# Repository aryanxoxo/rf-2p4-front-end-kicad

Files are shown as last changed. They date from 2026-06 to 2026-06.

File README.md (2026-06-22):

# 2.4 GHz RF Front-End KiCad Project

> Public archive note: this repository is a portfolio/demo-safe version prepared from private working repositories/materials; sensitive details, credentials, raw logs, and proprietary context are intentionally omitted.

This is a real KiCad project scaffold for a compact 2.4 GHz RF front end, not a portfolio mockup.

## What Is Included

- `rf_2p4_front_end.kicad_pro`: KiCad project file with an RF netclass.
- `rf_2p4_front_end.kicad_pcb`: Two-layer PCB layout with board outline, edge-launch SMA pads, 50 ohm RF routes, 0402 matching parts, SOT-363 RF amplifier footprint, ground pours, and via stitching.
- `rf_2p4_front_end.kicad_sch`: Schematic intent sheet with the RF signal chain and starting component values.
- `stackup_and_tuning_notes.md`: Fabrication, impedance, and VNA tuning notes.

## Stackup Assumption

The PCB is set up for a common low-cost two-layer FR-4 stackup:

- Board thickness: 1.6 mm
- Copper: 1 oz outer
- Dielectric: FR-4, Er about 4.2
- Top RF trace width: 3.0 mm nominal for approximately 50 ohm microstrip over a solid bottom ground plane

If your board house uses a different stackup, update the RF track width before ordering.

## Important Fabrication Notes

Open the project in KiCad and run DRC before fabrication. KiCad is not installed in this Codex environment, so Gerbers were not exported or validated here.

Before ordering, replace the generic SMA edge-launch and SOT-363 amplifier footprints with the exact manufacturer land patterns for your selected connector and RF amplifier. The included geometry is suitable as an editable RF layout starting point.

## Suggested Bring-Up

1. Populate J1/J2, C1, L1, C2, C3, and U1.
2. Start with C1 = 100 pF, L1 = 3.9 nH, C2 = 1.2 pF, C3 = 100 pF.
3. Calibrate the VNA to the SMA reference plane.
4. Measure S11 and S21 from 2.3 GHz to 2.6 GHz.
5. Re-tune L1/C2 to center the match across 2.4 GHz to 2.5 GHz.

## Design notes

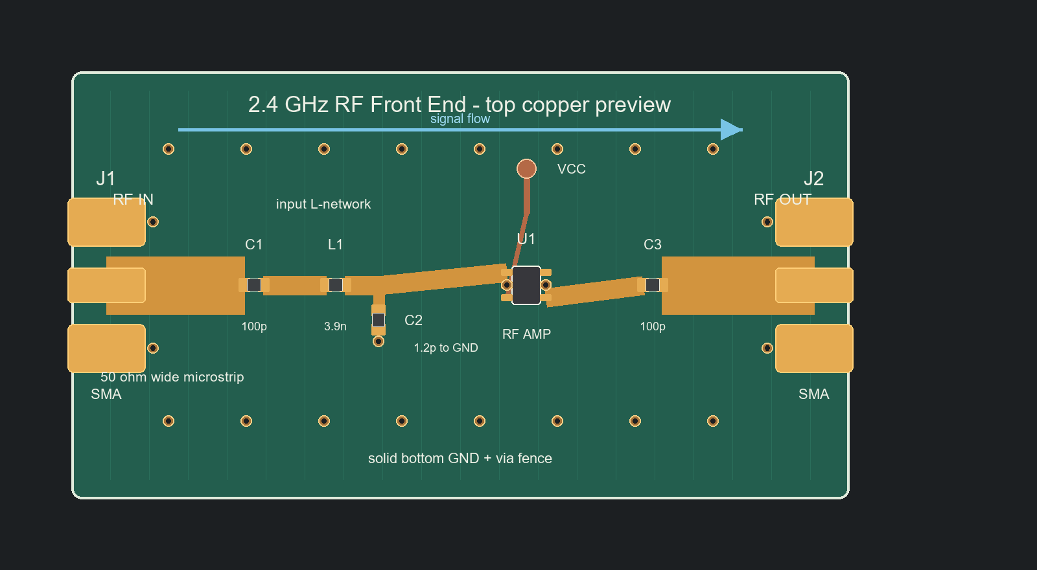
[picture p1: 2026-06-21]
rf_2p4_front_end_preview.png

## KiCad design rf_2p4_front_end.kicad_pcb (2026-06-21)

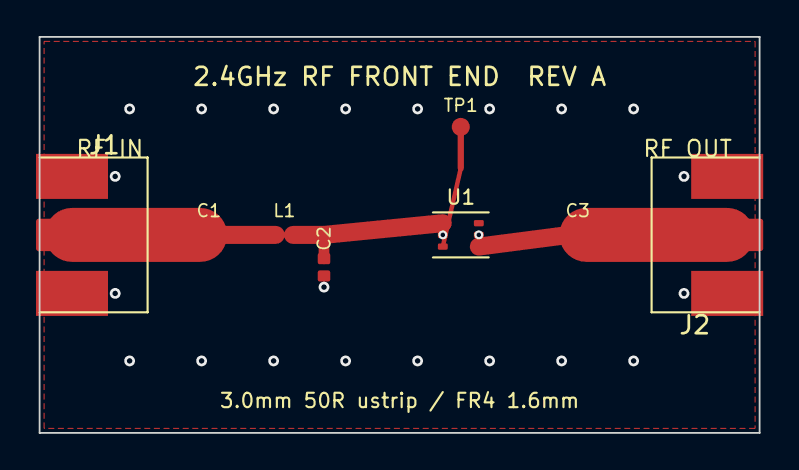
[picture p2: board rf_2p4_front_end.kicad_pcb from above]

Board: 2 copper layers, 40.0 x 22.0 mm, 8 parts (0 on the bottom side), 7 nets.

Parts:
C1, C3: 100pF; C_0402_RF
C2: 1.2pF; C_0402_Shunt
J1: SMA_EDGE; SMA_Edge_Launch_Input
J2: SMA_EDGE; SMA_Edge_Launch_Output
L1: 3.9nH; L_0402_RF
TP1: VCC; Bias_Test_Pads
U1: RF_AMP_SOT363; SOT-363_RF_AMP

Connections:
AMP_IN: C2.1, L1.2, U1.1
AMP_OUT: C3.1, U1.4
GND: C2.2, J1.2, J1.3, J2.2, J2.3, U1.2, U1.5
MATCH_NODE: C1.2, L1.1
RF_IN: C1.1, J1.1
RF_OUT: C3.2, J2.1
VCC: TP1.1, U1.3

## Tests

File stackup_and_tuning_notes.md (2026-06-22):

# Stackup, Impedance, and Tuning Notes

## 50 Ohm Trace

The board uses a 3.0 mm top-layer RF trace over a continuous bottom-layer ground plane. For a typical 1.6 mm FR-4 board with Er around 4.2 and 1 oz copper, this is in the practical range for a 50 ohm microstrip.

For tighter impedance control, ask the fabricator for the actual dielectric height and Er, then re-calculate trace width in KiCad's PCB Calculator or a field solver.

## SMA Launch

The SMA launch uses a wide center pad with adjacent ground pads and via stitching near the connector. The short transition from the launch pad into the RF trace should be tuned against the exact edge-launch connector datasheet.

Keep solder mask pulled back from the launch copper if your SMA connector application note recommends it.

## L-Network

The starting matching network is:

- C1: 100 pF input DC block
- L1: 3.9 nH series inductor
- C2: 1.2 pF shunt capacitor to ground
- C3: 100 pF output DC block

These are initial values for a plausible 2.4 GHz amplifier input match. Replace them with values from the selected amplifier S-parameters and tune after assembly.

## VNA Tuning Flow

1. Calibrate at the SMA plane.
2. Measure the unpowered input match if the amplifier datasheet permits it, or bias the amplifier per datasheet for active S-parameter measurement.
3. If the S11 minimum is low-frequency shifted, reduce series inductance or shunt capacitance.
4. If the S11 minimum is high-frequency shifted, increase series inductance or shunt capacitance.
5. Confirm S11 below -15 dB across 2.4 GHz to 2.5 GHz.
6. Confirm S21 is flat enough for the system budget.

## DRC / Gerber

Open `rf_2p4_front_end.kicad_pro` in KiCad, refill zones, run DRC, and export Gerbers/drill files after selecting exact production footprints.
